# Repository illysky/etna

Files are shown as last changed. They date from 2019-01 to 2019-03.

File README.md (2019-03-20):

**Etna - 120W DC Soldering Controller for JBC T245 Soldering Handles with PID Control, OLED, and Bluetooth LE**

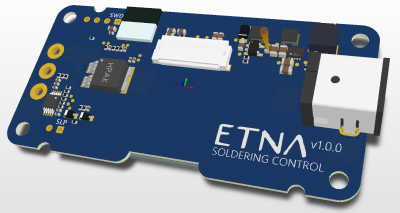
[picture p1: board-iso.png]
Title


Etna is a open source soldering iron controller for the JBC T245 type soldering handles with PID Control, Bluetooth LE and OLED - all powered from a variable DC source. 

JBC make great soldering irons such as the T-245 that allow for quick swap tips with an integrated thermocouple for fantastic temperature response. However, I needed the controller to be portable - ie, small, lightweight and run from a DC source such as a laptop supply or a battery pack. Secondly, I found the JBC controllers to be expensive despite all magic being in their lower cost handles.

**Features**

- Fully Open Source
- PID Temperature Control
- Powered from a 5-19VDC power source (eg, 120W 18V laptop supply or 18V 18650 battery pack - not supplied)
- Small and Lightweight - (70mm x 30mm @ 20g)
- Bluetooth LE (Configurable with app- Coming Soon!)
- 1.5" OLED Display with buttons and sounder
- Power monitoring with overcurrent protection
- Sleep function via grounding the cradle detect
- ST Micro VN5E010AH 10mR high-side driver for cool operation
- Firmware can be adapted for other soldering irons by adjusting thermocouple lookup tables
- Enclosure 3D model available for printing

Etna - let the solder flow ;) 

**Links**

- [T245 Handles](https://www.jbctools.com/t245-a-general-purpose-handle-product-45-category-5-menu-70.html) 
- [Power Supply](https://www.amazon.co.uk/dp/B01DIY8OTI)

Available on Tindie Soon!

**Thanks**  
Thank you to [@timothyjager](https://github.com/timothyjager/JBC-Soldering-Controller) for inspiring me to use the VN5E010AH and ADS1114.

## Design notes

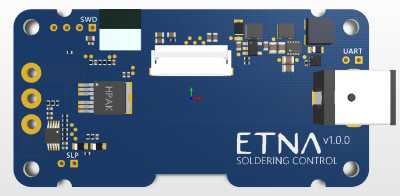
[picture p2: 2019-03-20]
board-top.png

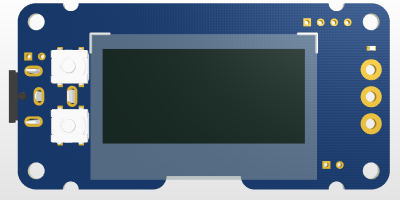
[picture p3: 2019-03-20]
board-bottom.png

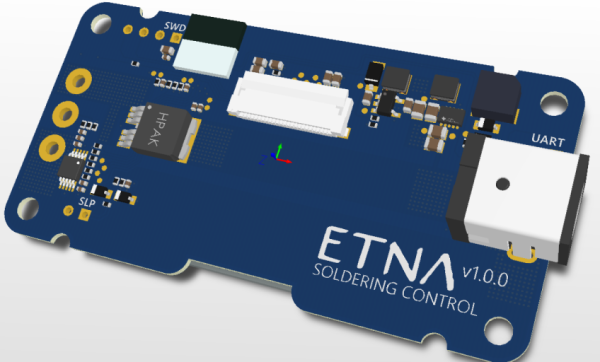
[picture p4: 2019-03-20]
board-image.png

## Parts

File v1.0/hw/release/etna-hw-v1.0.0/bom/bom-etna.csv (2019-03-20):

Designator | Quantity | Comment | Footprint
P101 | 1 |  | 3x3x3
C300, C504 | 2 | 1u | 0402-capacitor
C400, C401, C500, C501, C503, C601, C606 | 7 | 100n | 0402-capacitor
C502 | 1 | 10nF | 0402-capacitor
C505 | 1 | 100p | 0402-capacitor
R200, R500, R600 | 3 | 100K | 0402-resistor
R201 | 1 | 11.8K | 0402-resistor
R400, R402, R403, R404, R405 | 5 | 10K | 0402-resistor
R401 | 1 | 90K | 0402-resistor
R501 | 1 | 1K | 0402-resistor
R502 | 1 | 10R | 0402-resistor
R503 | 1 | 4M7 | 0402-resistor
R504 | 1 | 470R | 0402-resistor
R505, R506, R507, R508 | 4 | 51R | 0402-resistor
R509, R602 | 2 | 0R | 0402-resistor
R601 | 1 | 910K | 0402-resistor
C204 | 1 | 2u2 | 0603-capacitor
C205 | 1 | 2u2 (16V) | 0603-capacitor
C301 | 1 | 10u | 0603-capacitor
C600, C602, C604 | 3 | 4u7 | 0603-capacitor
C603 | 1 | 100n | 0603-capacitor
C605 | 1 | 1u | 0603-capacitor
D601 | 1 | ASMT-CB20 | 0603-LED
C200, C201 | 2 | 2u2 (35V) | 0805-CAP
C202, C203 | 2 | 22u | 0805-CAP
S600, S601 | 2 | B3SE-1002P | B3SE-1002P
P300, P500 | 2 |  | HDR1X2
P301 | 1 |  | HDR1X4
Q400 | 1 | VN5E010AH | HPAK6
U300 | 1 | ISP1507 | ISP1507
P600 | 1 | KSSG23J12 | KSSG23J12
P100 | 1 | PJ-063AH | PJ-063AH
D200 | 1 | 1N5819HW-7-F | SOD123-DIODE
D500, D501, D600 | 3 | PMEG2010EA,115 | SOD-323
U201 | 1 | AP3012 | SOT-235
L200, L201 | 2 | SRN3015-100M | SRN3015
TP200, TP201, TP202, TP203, TP204, TP400, TP401, TP402, TP403, TP500, TP501, TP502, TP503, TP600, TP601, TP602, TP603, TP604, TP605, TP606, TP607 | 21 | TP | TESTPOINT
Q600 | 1 | DMN2050LFDB | U-DFN2020-6
U500 | 1 | ADS1118 | VSSOP-10
U200 | 1 | TPS62177 | WSON10
LCD600 | 1 | ER-OLED015-2 | XF2M-2415-1A-REV

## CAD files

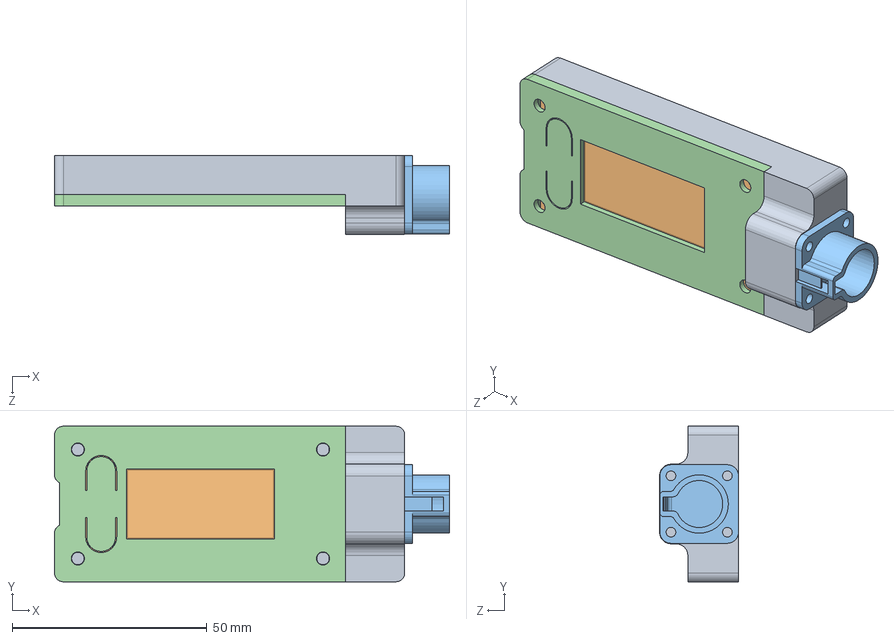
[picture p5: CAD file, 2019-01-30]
v1.0/me/ass-long.SLDASM
101.5 x 40.0 x 20.3 mm
etna
pcb01-main
RPC1-12RB-6P
etna-top

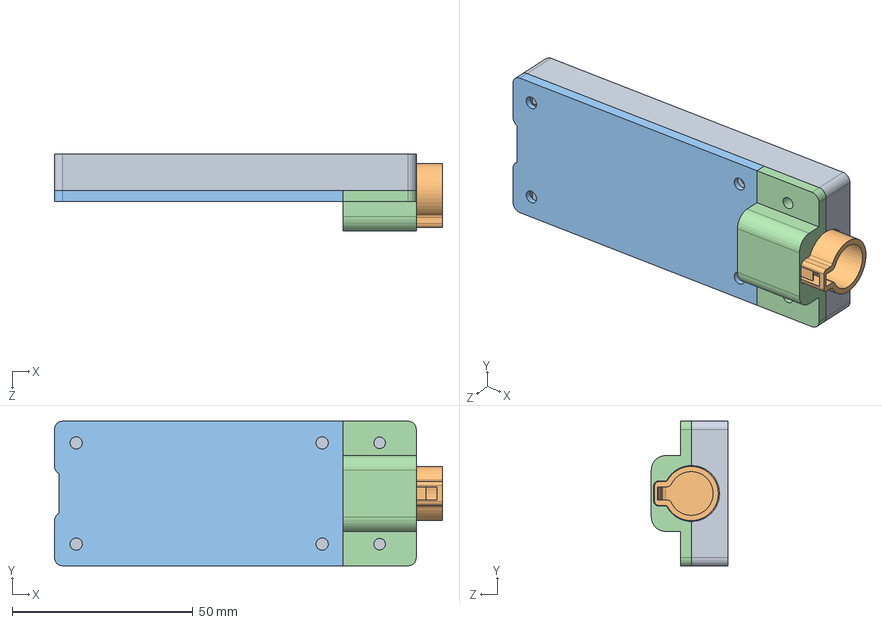
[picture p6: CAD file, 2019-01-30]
v1.0/me/Assem1.SLDASM
107.2 x 40.0 x 21.1 mm
etna-long
RPC1-12RB-6P
etna-top-ling
etna-cover

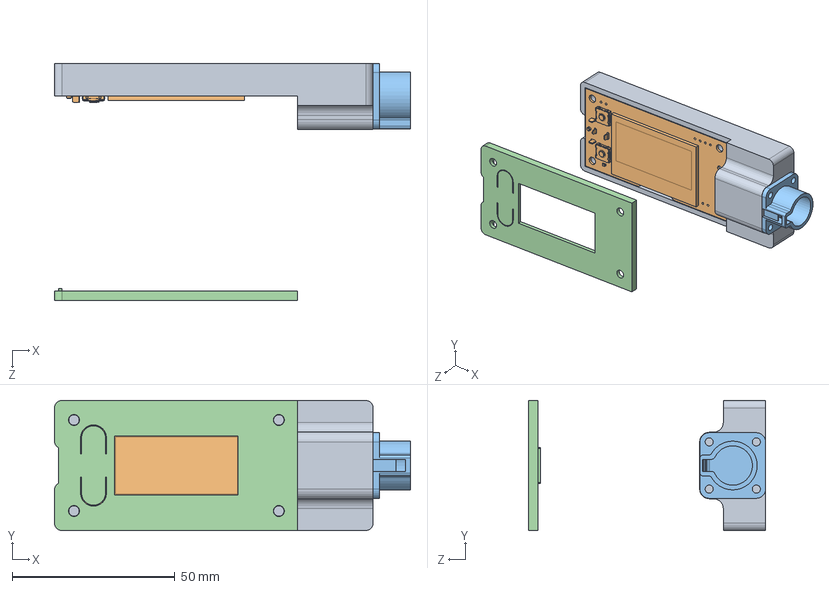
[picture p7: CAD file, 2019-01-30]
v1.0/me/Assem2.SLDASM
109.5 x 40.0 x 73.0 mm
etna-new
pcb01-main
RPC1-12RB-6P
etna-top

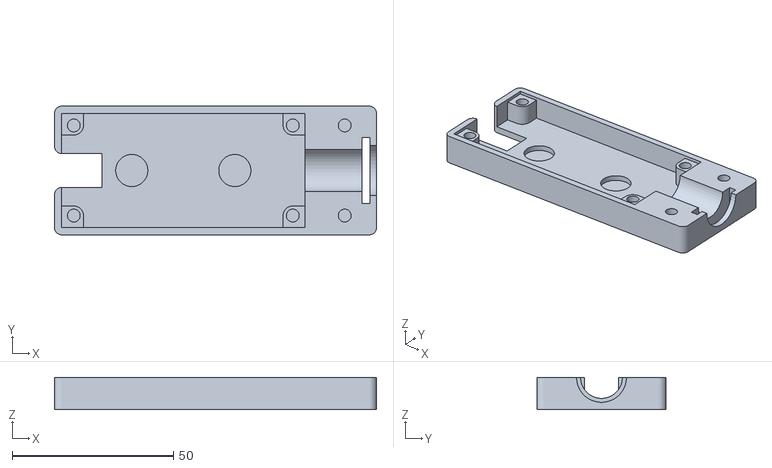
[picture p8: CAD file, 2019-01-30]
v1.0/me/etna/etna-long.STL
100.0 x 40.0 x 10.0

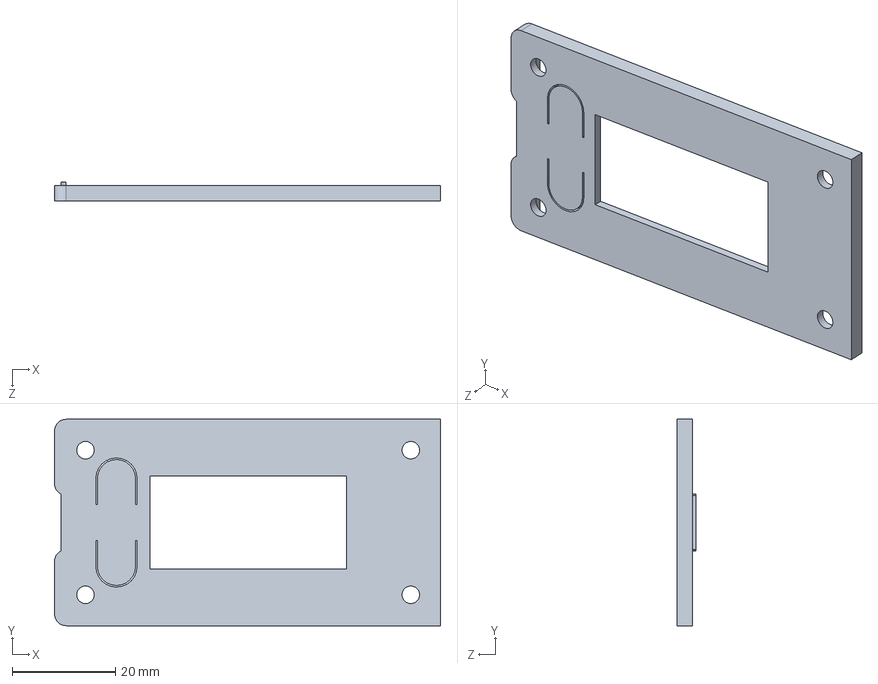
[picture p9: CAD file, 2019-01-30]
v1.0/me/etna-top.SLDPRT
74.8 x 40.0 x 3.70 mm

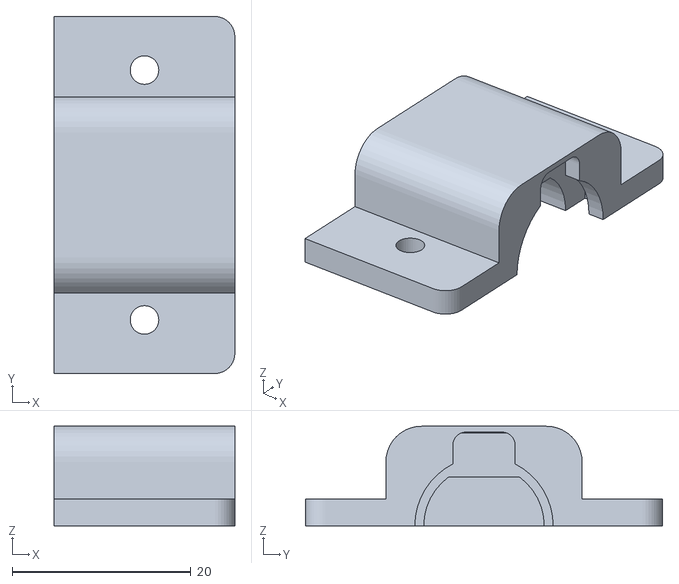
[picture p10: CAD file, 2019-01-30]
v1.0/me/etna/etna-cover.STL
20.2 x 40.0 x 11.1

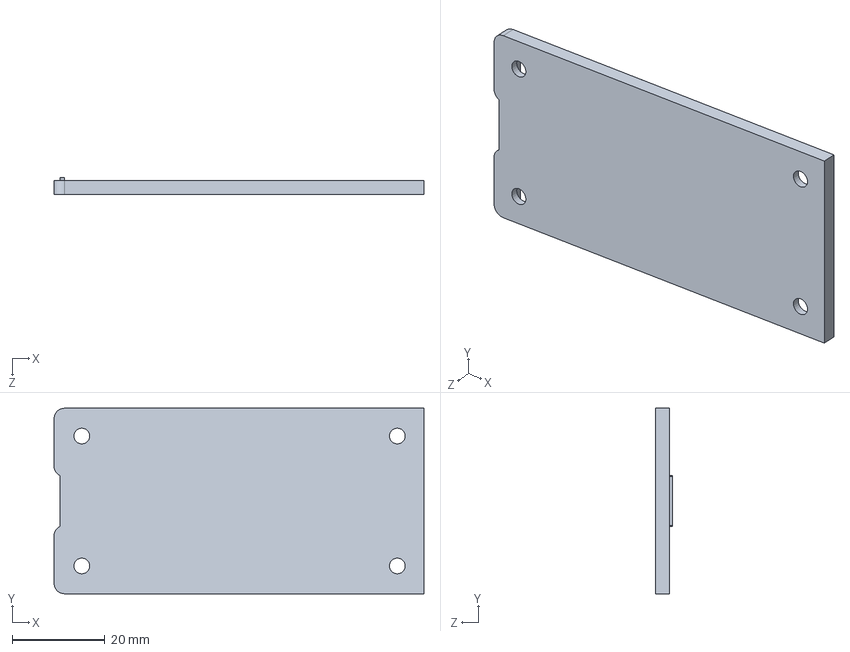
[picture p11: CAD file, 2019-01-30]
v1.0/me/etna-top-ling.SLDPRT
79.8 x 40.0 x 3.70 mm

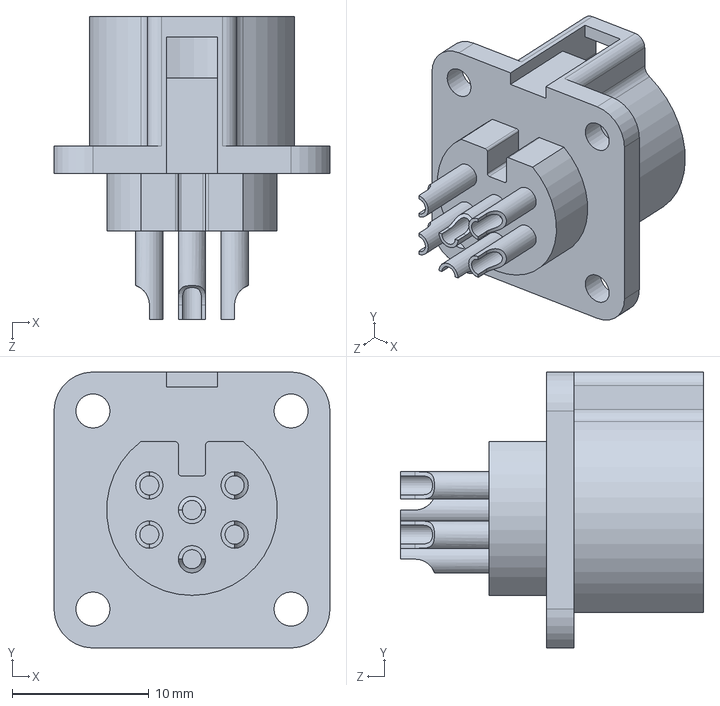
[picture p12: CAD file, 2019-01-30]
v1.0/me/RPC1-12RB-6P.SLDPRT
20.2 x 20.2 x 22.2 mm

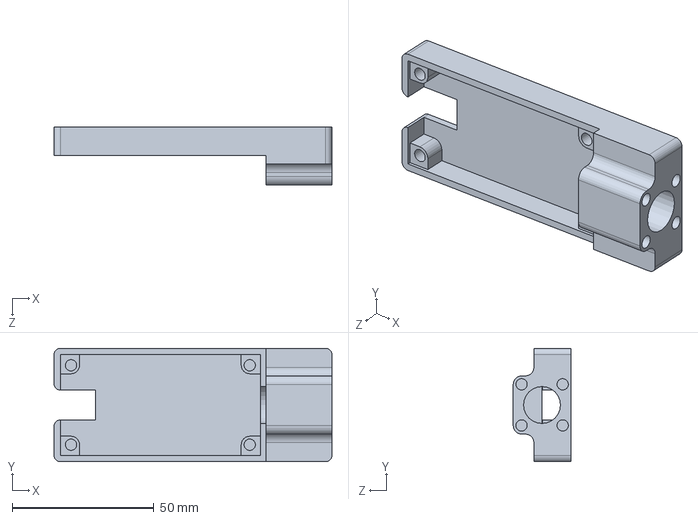
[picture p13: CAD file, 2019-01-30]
v1.0/me/etna-new.SLDPRT
98.0 x 40.0 x 20.3 mm

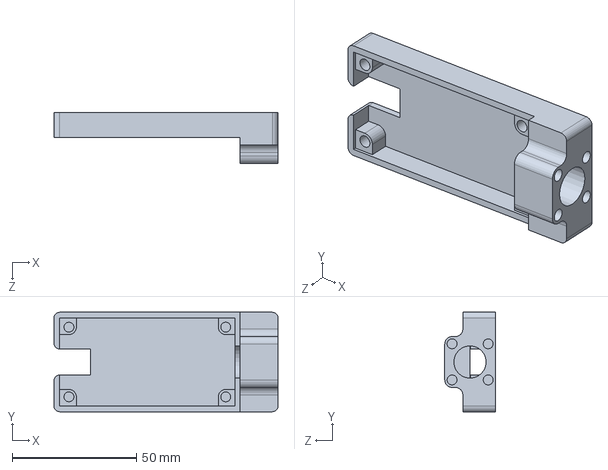
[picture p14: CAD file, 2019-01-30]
v1.0/me/etna.SLDPRT
90.0 x 40.0 x 20.3 mm

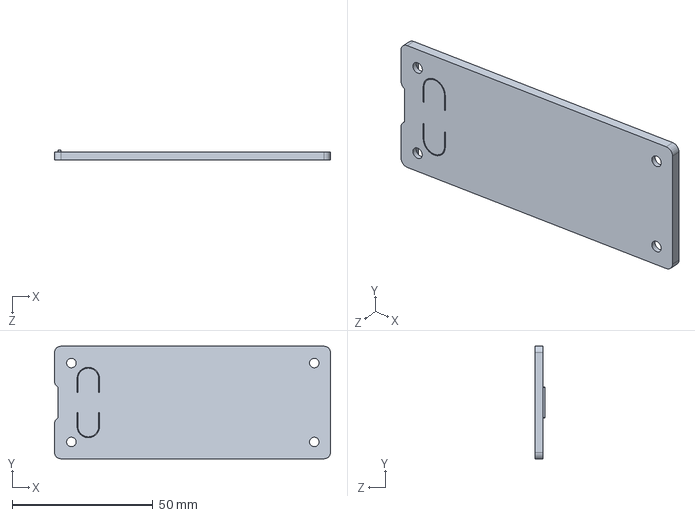
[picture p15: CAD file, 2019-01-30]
v1.0/me/etna-top-new.SLDPRT
98.0 x 40.0 x 3.70 mm

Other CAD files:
v1.0/me/etna/etna-top-ling.STL
v1.0/me/etna-cover.SLDPRT
v1.0/me/etna-long.SLDPRT

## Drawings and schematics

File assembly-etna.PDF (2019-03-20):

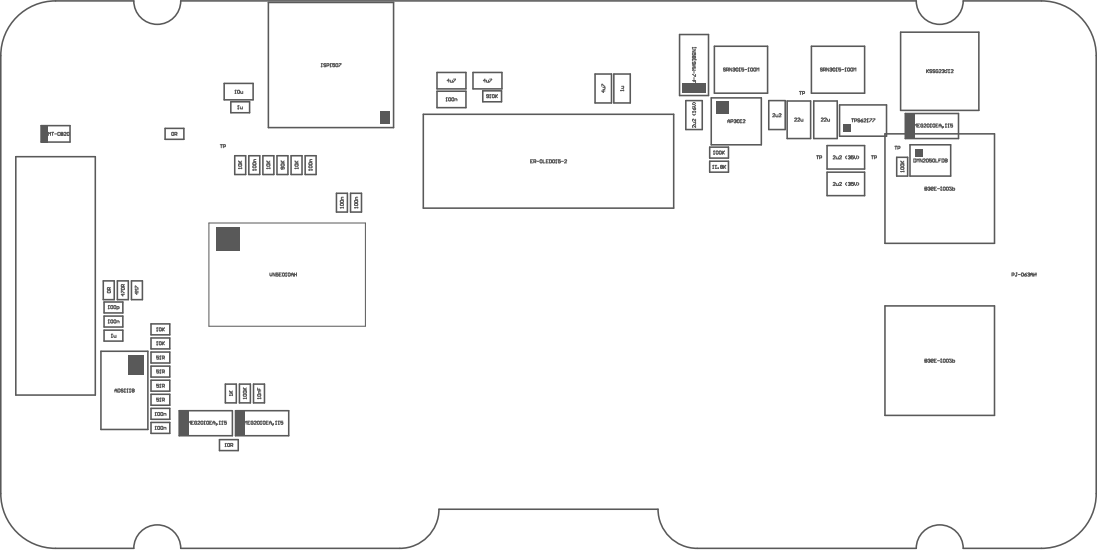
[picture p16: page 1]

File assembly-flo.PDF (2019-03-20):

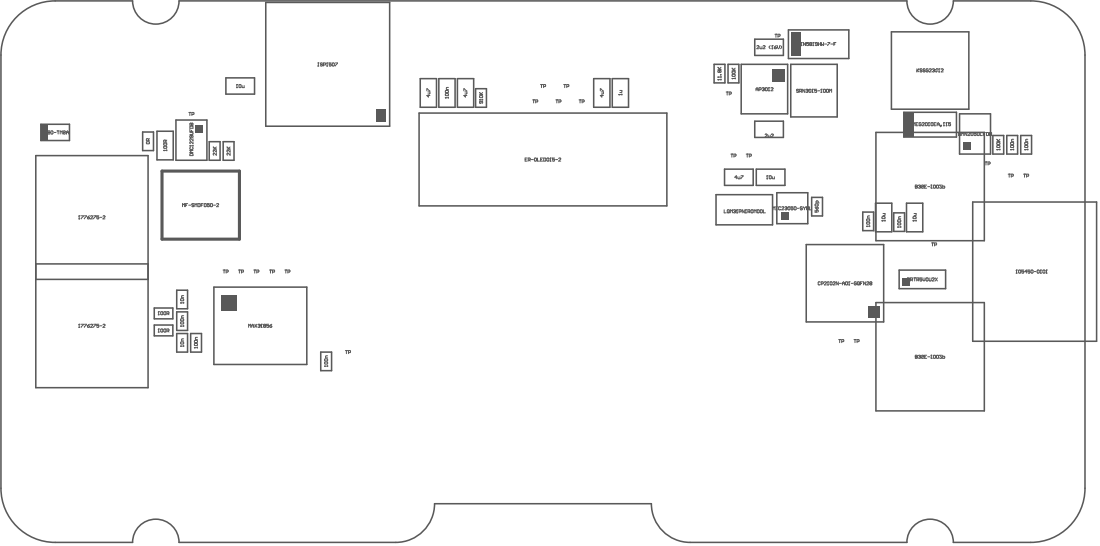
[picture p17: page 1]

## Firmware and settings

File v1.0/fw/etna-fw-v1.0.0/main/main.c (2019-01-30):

/*****************************************************************************************************************************************************************************************
 *
 * @file						
 * @brief 	
 * @version		
 * @author					
 * @date						
 *
*****************************************************************************************************************************************************************************************/

/****************************************************************************************************************************************************************************************
 * @include				
*****************************************************************************************************************************************************************************************/

// C
#include <stdint.h>
#include <string.h>

// Nordic
#include "nordic_common.h"
#include "nrf.h"
#include "nrf_delay.h"
#include "nrf_drv_twi.h"
#include "nrf_ble_gatt.h"
#include "nrf_drv_gpiote.h"
#include "nrf_drv_spi.h"
#include "nrf_drv_timer.h"
#include "nrf_drv_saadc.h"
#include "app_timer.h"
#include "app_error.h"
#include "fds.h"
#include "fstorage.h"
#define NRF_LOG_MODULE_NAME "APP"
#include "nrf_log.h"
#include "nrf_log_ctrl.h"

#include "app_uart.h"
#include "app_fifo.h"

// Nordic BLE
#include "ble.h"
#include "ble_hci.h"
#include "ble_srv_common.h"
#include "ble_advdata.h"
#include "ble_advertising.h"
#include "ble_bas.h"
#include "ble_hrs.h"
#include "ble_dis.h"
#include "ble_conn_params.h"
#include "ble_xpr.h"
#include "boards.h"
#include "softdevice_handler.h"
#include "bsp.h"
#include "bsp_btn_ble.h"
#include "ble_conn_state.h"
#include "peer_manager.h"

// Application
#include "app_config.h"
#include "hw_config.h"
#include "ads1118.h"

#include "arm_math.h"

/*****************************************************************************************************************************************************************************************
 * @globalvars				
*****************************************************************************************************************************************************************************************/
uint16_t								m_conn_handle = BLE_CONN_HANDLE_INVALID; 
ble_bas_t 							m_bas;                                   
nrf_ble_gatt_t 					m_gatt;    

const nrf_drv_spi_t APP_SPI0 = NRF_DRV_SPI_INSTANCE(0);  
const nrf_drv_spi_t APP_SPI1 = NRF_DRV_SPI_INSTANCE(1);  
const nrf_drv_timer_t APP_TIMER1 = NRF_DRV_TIMER_INSTANCE(1); 
const nrf_drv_timer_t APP_TIMER2 = NRF_DRV_TIMER_INSTANCE(2); 

/*****************************************************************************************************************************************************************************************
 * @localvars
*****************************************************************************************************************************************************************************************/
                   
//APP_TIMER_DEF(m_led_timer_id);   



#define PID_PARAM_KP        30.0f        /* Proporcional */
#define PID_PARAM_KI        1.0f        	/* Integral */
#define PID_PARAM_KD        0.36f      /* Derivative */

/*****************************************************************************************************************************************************************************************
 * @prototypes
*****************************************************************************************************************************************************************************************/



/***********************************************************************************************************************************************************//**
 * @function     	
 * @brief      	
***************************************************************************************************************************************************************/
static void app_pm_evt_handler(pm_evt_t const * p_evt)
{
    ret_code_t err_code;

    switch (p_evt->evt_id)
    {
        case PM_EVT_BONDED_PEER_CONNECTED:
        {
            NRF_LOG_INFO("Connected to a previously bonded device.\r\n");
        } break;

        case PM_EVT_CONN_SEC_SUCCEEDED:
        {
            NRF_LOG_INFO("Connection secured. Role: %d. conn_handle: %d, Procedure: %d\r\n",
                         ble_conn_state_role(p_evt->conn_handle),
                         p_evt->conn_handle,
                         p_evt->params.conn_sec_succeeded.procedure);
        } break;

        case PM_EVT_CONN_SEC_FAILED:
        {
            /* Often, when securing fails, it shouldn't be restarted, for security reasons.
             * Other times, it can be restarted directly.
             * Sometimes it can be restarted, but only after changing some Security Parameters.
             * Sometimes, it cannot be restarted until the link is disconnected and reconnected.
             * Sometimes it is impossible, to secure the link, or the peer device does not support it.
             * How to handle this error is highly application dependent. */
        } break;

        case PM_EVT_CONN_SEC_CONFIG_REQ:
        {
            // Reject pairing request from an already bonded peer.
            pm_conn_sec_config_t conn_sec_config = {.allow_repairing = false};
            pm_conn_sec_config_reply(p_evt->conn_handle, &conn_sec_config);
        } break;

        case PM_EVT_STORAGE_FULL:
        {
            // Run garbage collection on the flash.
            err_code = fds_gc();
            if (err_code == FDS_ERR_BUSY || err_code == FDS_ERR_NO_SPACE_IN_QUEUES)
            {
                // Retry.
            }
            else
            {
                APP_ERROR_CHECK(err_code);
            }
        } break;

        case PM_EVT_PEERS_DELETE_SUCCEEDED:
        {
           
        } break;

        case PM_EVT_LOCAL_DB_CACHE_APPLY_FAILED:
        {
            // The local database has likely changed, send service changed indications.
            pm_local_database_has_changed();
        } break;

        case PM_EVT_PEER_DATA_UPDATE_FAILED:
        {
            // Assert.
            APP_ERROR_CHECK(p_evt->params.peer_data_update_failed.error);
        } break;

        case PM_EVT_PEER_DELETE_FAILED:
        {
            // Assert.
            APP_ERROR_CHECK(p_evt->params.peer_delete_failed.error);
        } break;

        case PM_EVT_PEERS_DELETE_FAILED:
        {
            // Assert.
            APP_ERROR_CHECK(p_evt->params.peers_delete_failed_evt.error);
        } break;

        case PM_EVT_ERROR_UNEXPECTED:
        {
            // Assert.
            APP_ERROR_CHECK(p_evt->params.error_unexpected.error);
        } break;

        case PM_EVT_CONN_SEC_START:
        case PM_EVT_PEER_DATA_UPDATE_SUCCEEDED:
        case PM_EVT_PEER_DELETE_SUCCEEDED:
        case PM_EVT_LOCAL_DB_CACHE_APPLIED:
        case PM_EVT_SERVICE_CHANGED_IND_SENT:
        case PM_EVT_SERVICE_CHANGED_IND_CONFIRMED:
        default:
            break;
    }
}




/***********************************************************************************************************************************************************//**
 * @function     	
 * @brief      	
***************************************************************************************************************************************************************/
static void app_fds_evt_handler(fds_evt_t const * const p_evt)
{
    if (p_evt->id == FDS_EVT_GC)
    {
        NRF_LOG_DEBUG("GC completed\n");
    }
}

/***********************************************************************************************************************************************************//**
 * @function     	
 * @brief      	
***************************************************************************************************************************************************************/
static void app_gatt_evt_handler(nrf_ble_gatt_t * p_gatt, nrf_ble_gatt_evt_t * p_evt)
{
   
}


/***********************************************************************************************************************************************************//**
 * @function     	
 * @brief      	
***************************************************************************************************************************************************************/
static void app_adv_evt_handler(ble_adv_evt_t ble_adv_evt)
{

    switch (ble_adv_evt)
    {
        case BLE_ADV_EVT_FAST:
            break;
        case BLE_ADV_EVT_IDLE:
            break;
        default:
            break;
    }
}

/***********************************************************************************************************************************************************//**
 * @function     	
 * @brief      	
***************************************************************************************************************************************************************/
static void app_conn_params_evt_handler(ble_conn_params_evt_t * p_evt)
{
    uint32_t err_code;

    if (p_evt->evt_type == BLE_CONN_PARAMS_EVT_FAILED)
    {
        err_code = sd_ble_gap_disconnect(m_conn_handle, BLE_HCI_CONN_INTERVAL_UNACCEPTABLE);
        APP_ERROR_CHECK(err_code);
    }
}

/***********************************************************************************************************************************************************//**
 * @function     	
 * @brief      	
***************************************************************************************************************************************************************/
static void app_conn_params_error_handler(uint32_t nrf_error)
{
    APP_ERROR_HANDLER(nrf_error);
}


/***********************************************************************************************************************************************************//**
 * @function     	
 * @brief      	
***************************************************************************************************************************************************************/
static void assert_nrf_callback(uint16_t line_num, const uint8_t * p_file_name)
{
    app_error_handler(DEAD_BEEF, line_num, p_file_name);
}

/***********************************************************************************************************************************************************//**
 * @function     	
 * @brief      	
***************************************************************************************************************************************************************/
static void app_bluetooth_init (bool erase_bonds) 
{

		// Peer Manager Init **********************************************
		ble_gap_sec_params_t sec_param;
    ret_code_t           err_code;

    err_code = pm_init();
    APP_ERROR_CHECK(err_code);

    if (erase_bonds)
    {
        err_code = pm_peers_delete();
        APP_ERROR_CHECK(err_code);
    }

    memset(&sec_param, 0, sizeof(ble_gap_sec_params_t));

    // Security parameters to be used for all security procedures.
    sec_param.bond           = SEC_PARAM_BOND;
    sec_param.mitm           = SEC_PARAM_MITM;
    sec_param.io_caps        = SEC_PARAM_IO_CAPABILITIES;
    sec_param.oob            = SEC_PARAM_OOB;
    sec_param.min_key_size   = SEC_PARAM_MIN_KEY_SIZE;
    sec_param.max_key_size   = SEC_PARAM_MAX_KEY_SIZE;
    sec_param.kdist_own.enc  = 1;
    sec_param.kdist_own.id   = 1;
    sec_param.kdist_peer.enc = 1;
    sec_param.kdist_peer.id  = 1;

    err_code = pm_sec_params_set(&sec_param);
    APP_ERROR_CHECK(err_code);

    err_code = pm_register(app_pm_evt_handler);
    APP_ERROR_CHECK(err_code);

    err_code = fds_register(app_fds_evt_handler);
    APP_ERROR_CHECK(err_code);
	
		// GAP CONFIG *************************************************************************************************
		// Init **********************************************
    ble_gap_conn_params_t   gap_conn_params;
    ble_gap_conn_sec_mode_t sec_mode;
		ble_gap_addr_t		deviceAddress;
		uint8_t buf[14];
		
		// Set Device Name ***********************************
		sd_ble_gap_addr_get(&deviceAddress);
		sprintf((char*) buf, DEVICE_NAME, deviceAddress.addr[1],deviceAddress.addr[0]);
    BLE_GAP_CONN_SEC_MODE_SET_OPEN(&sec_mode);
    err_code = sd_ble_gap_device_name_set(&sec_mode, (const uint8_t *)buf, strlen((const char*)buf));
    APP_ERROR_CHECK(err_code);

		// Set Appearance ************************************
    err_code = sd_ble_gap_appearance_set(BLE_APPEARANCE_UNKNOWN);
    APP_ERROR_CHECK(err_code);
    memset(&gap_conn_params, 0, sizeof(gap_conn_params));

		// Set Connection Intervals ***************************
    gap_conn_params.min_conn_interval = MIN_CONN_INTERVAL;
    gap_conn_params.max_conn_interval = MAX_CONN_INTERVAL;
    gap_conn_params.slave_latency     = SLAVE_LATENCY;
    gap_conn_params.conn_sup_timeout  = CONN_SUP_TIMEOUT;

		// Set GAP *******************************************
    err_code = sd_ble_gap_ppcp_set(&gap_conn_params);
    APP_ERROR_CHECK(err_code);
		sd_ble_gap_tx_power_set(4);

		// GAP CONFIG *************************************************************************************************
		// Init **********************************************
	  err_code = nrf_ble_gatt_init(&m_gatt, app_gatt_evt_handler);
		APP_ERROR_CHECK(err_code);

		// SERVICE CONFIG *********************************************************************************************
    ble_bas_init_t bas_init;
    ble_dis_init_t dis_init;
    memset(&bas_init, 0, sizeof(bas_init));
    BLE_GAP_CONN_SEC_MODE_SET_OPEN(&bas_init.battery_level_char_attr_md.cccd_write_perm);
    BLE_GAP_CONN_SEC_MODE_SET_OPEN(&bas_init.battery_level_char_attr_md.read_perm);
    BLE_GAP_CONN_SEC_MODE_SET_NO_ACCESS(&bas_init.battery_level_char_attr_md.write_perm);
    BLE_GAP_CONN_SEC_MODE_SET_OPEN(&bas_init.battery_level_report_read_perm);
		
		// Battery Service ************************************
    bas_init.evt_handler          = NULL;
    bas_init.support_notification = true;
    bas_init.p_report_ref         = NULL;
    bas_init.initial_batt_level   = 100;
    err_code = ble_bas_init(&m_bas, &bas_init);
    APP_ERROR_CHECK(err_code);

		// Device Info Service *********************************
    memset(&dis_init, 0, sizeof(dis_init));
		sd_ble_gap_addr_get(&deviceAddress);
		sprintf((char*) buf, "%02X%02X%02X%02X%02X%02X", deviceAddress.addr[5], deviceAddress.addr[4], deviceAddress.addr[3], deviceAddress.addr[2],deviceAddress.addr[1],deviceAddress.addr[0]); 
    ble_srv_ascii_to_utf8(&dis_init.manufact_name_str, (char *)MANUFACTURER_NAME);
		ble_srv_ascii_to_utf8(&dis_init.model_num_str, DEVICE_MODEL);
		ble_srv_ascii_to_utf8(&dis_init.serial_num_str, (char*) buf);
		ble_srv_ascii_to_utf8(&dis_init.fw_rev_str, DEVICE_FW);	
		ble_srv_ascii_to_utf8(&dis_init.hw_rev_str, DEVICE_HW);	
    BLE_GAP_CONN_SEC_MODE_SET_OPEN(&dis_init.dis_attr_md.read_perm);
    BLE_GAP_CONN_SEC_MODE_SET_NO_ACCESS(&dis_init.dis_attr_md.write_perm);
    err_code = ble_dis_init(&dis_init);
    APP_ERROR_CHECK(err_code);
		
		
		xpr_bluetooth_init (); 
		
		// ADV CONFIG ************************************************************************************************
    ble_advdata_t          	advdata;
    ble_adv_modes_config_t 	options;
		ble_uuid_t    					service_uuid;
		service_uuid.type=xpr_peripheral.uuid; 
		service_uuid.uuid=XPR_SERVICE_UUID; 

    // Build advertising data struct to pass into @ref ble_advertising_init.
    memset(&advdata, 0, sizeof(advdata));
    advdata.name_type               			= BLE_ADVDATA_FULL_NAME;
    advdata.include_appearance     			 	= false;
    advdata.flags                   			= BLE_GAP_ADV_FLAGS_LE_ONLY_GENERAL_DISC_MODE;
		advdata.uuids_more_available.uuid_cnt = 1;
    advdata.uuids_more_available.p_uuids  = &service_uuid;
    memset(&options, 0, sizeof(options));
    options.ble_adv_fast_enabled  				= true;
    options.ble_adv_fast_interval 				= APP_ADV_INTERVAL;
		options.ble_adv_fast_timeout  				= 60;
    err_code = ble_advertising_init(&advdata, NULL, &options, app_adv_evt_handler, NULL);
    APP_ERROR_CHECK(err_code);
		
		// Connection Parameters *********************************************************************
    ble_conn_params_init_t cp_init;
    memset(&cp_init, 0, sizeof(cp_init));
    cp_init.p_conn_params                  = NULL;
    cp_init.first_conn_params_update_delay = FIRST_CONN_PARAMS_UPDATE_DELAY;
    cp_init.next_conn_params_update_delay  = NEXT_CONN_PARAMS_UPDATE_DELAY;
    cp_init.max_conn_params_update_count   = MAX_CONN_PARAMS_UPDATE_COUNT;
    cp_init.start_on_notify_cccd_handle    = xpr_peripheral.data_characteristic.cccd_handle;
    cp_init.disconnect_on_fail             = false;
    cp_init.evt_handler                    = app_conn_params_evt_handler;
    cp_init.error_handler                  = app_conn_params_error_handler;
    err_code = ble_conn_params_init(&cp_init);
    APP_ERROR_CHECK(err_code);
		

 }



/***********************************************************************************************************************************************************//**
 * @function     	
 * @brief      	
***************************************************************************************************************************************************************/
static void app_start_bluetooth_adv (void)
{
    ret_code_t err_code;
    err_code = ble_advertising_start(BLE_ADV_MODE_FAST);
    APP_ERROR_CHECK(err_code);
}
















/***********************************************************************************************************************************************************//**
 * @function     	
 * @brief      	
***************************************************************************************************************************************************************/
static void app_timers_init(void)
{
			uint32_t err_code;

//    // Initialize timer module.
			APP_TIMER_INIT(APP_TIMER_PRESCALER, APP_TIMER_OP_QUEUE_SIZE, false);


//		err_code = app_timer_create(&m_battery_timer_id,APP_TIMER_MODE_REPEATED,app_battery_timer);
//		APP_ERROR_CHECK(err_code);
	
}


/***********************************************************************************************************************************************************//**
 * @function     	
 * @brief      	
***************************************************************************************************************************************************************/
static void app_start_timers (void)
{
	
//	uint32_t err_code;
//	err_code = app_timer_start (m_led_timer_id, APP_TIMER_TICKS(100, APP_TIMER_PRESCALER), NULL); 
//	APP_ERROR_CHECK(err_code);
//	
//	
//	err_code = app_timer_start (m_battery_timer_id, APP_TIMER_TICKS(3000, APP_TIMER_PRESCALER), NULL); 
//	APP_ERROR_CHECK(err_code);
//	
	
}









/***********************************************************************************************************************************************************//**
 * @function     	
 * @brief      	
***************************************************************************************************************************************************************/
static void app_sleep (void)
{
    uint32_t err_code = bsp_indication_set(BSP_INDICATE_IDLE);
    APP_ERROR_CHECK(err_code);
    err_code = bsp_btn_ble_sleep_mode_prepare();
    APP_ERROR_CHECK(err_code);
    err_code = sd_power_system_off();
    APP_ERROR_CHECK(err_code);
}
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
int main(void)
 {
  	app_timers_init();
	app_ble_stack_init();
	app_hardware_init();
	
	 
	pid.Kp = PID_PARAM_KP;        /* Proporcional */
  pid.Ki = PID_PARAM_KI;        /* Integral */
  pid.Kd = PID_PARAM_KD;        /* Derivative */
	 
	arm_pid_init_f32(&pid, 1);
	 
	nrf_drv_timer_enable(&APP_TIMER1);
	nrf_drv_timer_enable(&APP_TIMER2);
	while (1); 

	
	
	
	
	
	app_bluetooth_init(true);
  app_start_bluetooth_adv();

	// Enter main loop.
  for (;;)
	{
		if (NRF_LOG_PROCESS() == false)
		{
				app_power_manage();
		}
  }
}

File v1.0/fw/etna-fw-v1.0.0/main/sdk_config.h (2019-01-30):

#ifndef SDK_CONFIG_H
#define SDK_CONFIG_H
// <<< Use Configuration Wizard in Context Menu >>>\n
#ifdef USE_APP_CONFIG
#include "app_config.h"
#endif
// <h> Application 

//==========================================================
// <o> NRF_BLE_CENTRAL_LINK_COUNT - Number of central links 
#ifndef NRF_BLE_CENTRAL_LINK_COUNT
#define NRF_BLE_CENTRAL_LINK_COUNT 0
#endif

// <o> NRF_BLE_CENTRAL_LINK_COUNT - Number of central links 
#ifndef NRF_BLE_CENTRAL_LINK_COUNT
#define NRF_BLE_CENTRAL_LINK_COUNT 0
#endif

// <o> NRF_BLE_PERIPHERAL_LINK_COUNT - Number of peripheral links 
#ifndef NRF_BLE_PERIPHERAL_LINK_COUNT
#define NRF_BLE_PERIPHERAL_LINK_COUNT 1
#endif

// <o> NRF_BLE_PERIPHERAL_LINK_COUNT - Number of peripheral links 
#ifndef NRF_BLE_PERIPHERAL_LINK_COUNT
#define NRF_BLE_PERIPHERAL_LINK_COUNT 1
#endif

// </h> 
//==========================================================

// <h> nRF_BLE 

//==========================================================
// <q> BLE_ADVERTISING_ENABLED  - ble_advertising - Advertising module
 

#ifndef BLE_ADVERTISING_ENABLED
#define BLE_ADVERTISING_ENABLED 1
#endif

// <q> BLE_DTM_ENABLED  - ble_dtm - Module for testing RF/PHY using DTM commands
 

#ifndef BLE_DTM_ENABLED
#define BLE_DTM_ENABLED 0
#endif

// <q> BLE_RACP_ENABLED  - ble_racp - Record Access Control Point library
 

#ifndef BLE_RACP_ENABLED
#define BLE_RACP_ENABLED 0
#endif

// <e> NRF_BLE_GATT_ENABLED - nrf_ble_gatt - GATT module
//==========================================================
#ifndef NRF_BLE_GATT_ENABLED
#define NRF_BLE_GATT_ENABLED 1
#endif
#if  NRF_BLE_GATT_ENABLED
// <o> NRF_BLE_GATT_MAX_MTU_SIZE - Static maximum MTU size that is passed to the @ref sd_ble_enable function. 
#ifndef NRF_BLE_GATT_MAX_MTU_SIZE
#define NRF_BLE_GATT_MAX_MTU_SIZE 158
#endif

#endif //NRF_BLE_GATT_ENABLED
// </e>

// <q> NRF_BLE_QWR_ENABLED  - nrf_ble_qwr - Queued writes support module (prepare/execute write)
 

#ifndef NRF_BLE_QWR_ENABLED
#define NRF_BLE_QWR_ENABLED 0
#endif

// <q> PEER_MANAGER_ENABLED  - peer_manager - Peer Manager
 

#ifndef PEER_MANAGER_ENABLED
#define PEER_MANAGER_ENABLED 1
#endif

// </h> 
//==========================================================

// <h> nRF_BLE_Services 

//==========================================================
// <q> BLE_ANCS_C_ENABLED  - ble_ancs_c - Apple Notification Service Client
 

#ifndef BLE_ANCS_C_ENABLED
#define BLE_ANCS_C_ENABLED 0
#endif

// <q> BLE_ANS_C_ENABLED  - ble_ans_c - Alert Notification Service Client
 

#ifndef BLE_ANS_C_ENABLED
#define BLE_ANS_C_ENABLED 0
#endif

// <q> BLE_BAS_C_ENABLED  - ble_bas_c - Battery Service Client
 

#ifndef BLE_BAS_C_ENABLED
#define BLE_BAS_C_ENABLED 0
#endif

// <q> BLE_BAS_ENABLED  - ble_bas - Battery Service
 

#ifndef BLE_BAS_ENABLED
#define BLE_BAS_ENABLED 1
#endif

// <q> BLE_CSCS_ENABLED  - ble_cscs - Cycling Speed and Cadence Service
 

#ifndef BLE_CSCS_ENABLED
#define BLE_CSCS_ENABLED 0
#endif

// <q> BLE_CTS_C_ENABLED  - ble_cts_c - Current Time Service Client
 

#ifndef BLE_CTS_C_ENABLED
#define BLE_CTS_C_ENABLED 0
#endif

// <q> BLE_DIS_ENABLED  - ble_dis - Device Information Service
 

#ifndef BLE_DIS_ENABLED
#define BLE_DIS_ENABLED 1
#endif

// <q> BLE_GLS_ENABLED  - ble_gls - Glucose Service
 

#ifndef BLE_GLS_ENABLED
#define BLE_GLS_ENABLED 0
#endif

// <q> BLE_HIDS_ENABLED  - ble_hids - Human Interface Device Service
 

#ifndef BLE_HIDS_ENABLED
#define BLE_HIDS_ENABLED 0
#endif

// <e> BLE_HRS_C_ENABLED - ble_hrs_c - Heart Rate Service Client
//==========================================================
#ifndef BLE_HRS_C_ENABLED
#define BLE_HRS_C_ENABLED 0
#endif
#if  BLE_HRS_C_ENABLED
// <o> BLE_HRS_C_RR_INTERVALS_MAX_CNT - Maximum number of RR_INTERVALS per notification to be decoded 
#ifndef BLE_HRS_C_RR_INTERVALS_MAX_CNT
#define BLE_HRS_C_RR_INTERVALS_MAX_CNT 30
#endif

#endif //BLE_HRS_C_ENABLED
// </e>

// <q> BLE_HRS_ENABLED  - ble_hrs - Heart Rate Service
 

#ifndef BLE_HRS_ENABLED
#define BLE_HRS_ENABLED 1
#endif

// <q> BLE_HTS_ENABLED  - ble_hts - Health Thermometer Service
 

#ifndef BLE_HTS_ENABLED
#define BLE_HTS_ENABLED 0
#endif

// <q> BLE_IAS_C_ENABLED  - ble_ias_c - Immediate Alert Service Client
 

#ifndef BLE_IAS_C_ENABLED
#define BLE_IAS_C_ENABLED 0
#endif

// <q> BLE_IAS_ENABLED  - ble_ias - Immediate Alert Service
 

#ifndef BLE_IAS_ENABLED
#define BLE_IAS_ENABLED 0
#endif

// <q> BLE_LBS_C_ENABLED  - ble_lbs_c - Nordic LED Button Service Client
 

#ifndef BLE_LBS_C_ENABLED
#define BLE_LBS_C_ENABLED 0
#endif

// <q> BLE_LBS_ENABLED  - ble_lbs - LED Button Service
 

#ifndef BLE_LBS_ENABLED
#define BLE_LBS_ENABLED 0
#endif

// <q> BLE_LLS_ENABLED  - ble_lls - Link Loss Service
 

#ifndef BLE_LLS_ENABLED
#define BLE_LLS_ENABLED 0
#endif

// <q> BLE_NUS_C_ENABLED  - ble_nus_c - Nordic UART Central Service
 

#ifndef BLE_NUS_C_ENABLED
#define BLE_NUS_C_ENABLED 0
#endif

// <q> BLE_NUS_ENABLED  - ble_nus - Nordic UART Service
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

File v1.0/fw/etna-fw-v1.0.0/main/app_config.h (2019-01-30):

/**
 * @file        		app_cfg.h 
 * @brief           Configures the application
 * @author         	Illysky Ltd
 * @project         Insight
 *
*/

#ifndef __app_cfg_h
#define __app_cfg_h


#define IS_SRVC_CHANGED_CHARACT_PRESENT  1                                           /**< Include or not the service_changed characteristic. if not enabled, the server's database cannot be changed for the lifetime of the device*/

#define MANUFACTURER_NAME                "Xelba"                       			 /**< Manufacturer. Will be passed to Device Information Service. */
#define DEVICE_NAME              				 "XP-%02X%02X"                             	 /**< Name of device. Will be included in the advertising data. */
#define DEVICE_MODEL										 "Probe"
#define DEVICE_FW												 "v1.0.0"
#define DEVICE_HW												 "v1.0.0"

#define APP_ADV_INTERVAL                 300                                         /**< The advertising interval (in units of 0.625 ms. This value corresponds to 187.5 ms). */
#define APP_ADV_TIMEOUT_IN_SECONDS       30                                         /**< The advertising timeout in units of seconds. */

#define APP_TIMER_PRESCALER              0                                           /**< Value of the RTC1 PRESCALER register. */
#define APP_TIMER_OP_QUEUE_SIZE          4                                           /**< Size of timer operation queues. */

#define BUTTON_DETECTION_DELAY     			 APP_TIMER_TICKS(50, APP_TIMER_PRESCALER)   /**< Delay from a GPIOTE event until a button is reported as pushed (in number of timer ticks). */

#define BATTERY_LEVEL_MEAS_INTERVAL      APP_TIMER_TICKS(2000, APP_TIMER_PRESCALER)  /**< Battery level measurement interval (ticks). */
#define MIN_BATTERY_LEVEL                81                                          /**< Minimum simulated battery level. */
#define MAX_BATTERY_LEVEL                100                                         /**< Maximum simulated 7battery level. */
#define BATTERY_LEVEL_INCREMENT          1                                           /**< Increment between each simulated battery level measurement. */


#define MIN_CONN_INTERVAL                MSEC_TO_UNITS(25, UNIT_1_25_MS)            /**< Minimum acceptable connection interval (0.4 seconds). */
#define MAX_CONN_INTERVAL                MSEC_TO_UNITS(70, UNIT_1_25_MS)            /**< Maximum acceptable connection interval (0.65 second). */
#define SLAVE_LATENCY                    0                                           /**< Slave latency. */
#define CONN_SUP_TIMEOUT                 MSEC_TO_UNITS(4000, UNIT_10_MS)             /**< Connection supervisory timeout (4 seconds). */

#define FIRST_CONN_PARAMS_UPDATE_DELAY   APP_TIMER_TICKS(5000, APP_TIMER_PRESCALER)  /**< Time from initiating event (connect or start of notification) to first time sd_ble_gap_conn_param_update is called (5 seconds). */
#define NEXT_CONN_PARAMS_UPDATE_DELAY    APP_TIMER_TICKS(30000, APP_TIMER_PRESCALER) /**< Time between each call to sd_ble_gap_conn_param_update after the first call (30 seconds). */
#define MAX_CONN_PARAMS_UPDATE_COUNT     3                                           /**< Number of attempts before giving up the connection parameter negotiation. */

#define SEC_PARAM_BOND                   1                                           /**< Perform bonding. */
#define SEC_PARAM_MITM                   0                                           /**< Man In The Middle protection not required. */
#define SEC_PARAM_LESC                   0                                           /**< LE Secure Connections not enabled. */
#define SEC_PARAM_KEYPRESS               0                                           /**< Keypress notifications not enabled. */
#define SEC_PARAM_IO_CAPABILITIES        BLE_GAP_IO_CAPS_NONE                        /**< No I/O capabilities. */
#define SEC_PARAM_OOB                    0                                           /**< Out Of Band data not available. */
#define SEC_PARAM_MIN_KEY_SIZE           7                                           /**< Minimum encryption key size. */
#define SEC_PARAM_MAX_KEY_SIZE           16                                          /**< Maximum encryption key size. */

#define DEAD_BEEF                        0xDEADBEEF                                  /**< Value used as error code on stack dump, can be used to identify stack location on stack unwind. */

#define APP_FEATURE_NOT_SUPPORTED        BLE_GATT_STATUS_ATTERR_APP_BEGIN + 2        /**< Reply when unsupported features are requested. */



#endif /* __stdint_h */
